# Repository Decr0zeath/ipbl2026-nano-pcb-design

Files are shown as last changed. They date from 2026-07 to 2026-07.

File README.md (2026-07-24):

# Nano Quadruped Robot PCB Design - iPBL 2026

A KiCad-based PCB design for servo motor control in a quadruped robot developed for the **International Project Based Learning (iPBL) 2026** program.

| Front | Side |
|---|---|
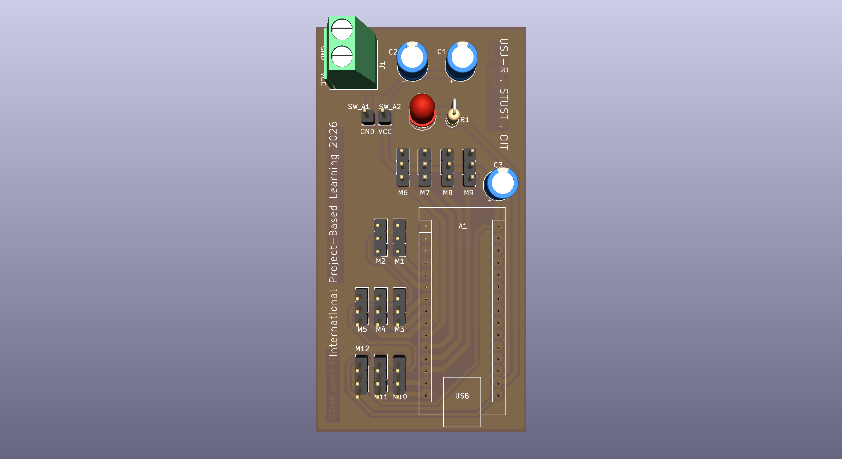
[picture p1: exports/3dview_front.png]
Expected 3D view, front
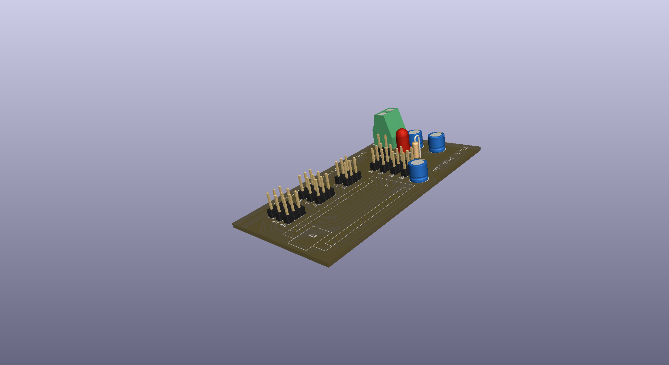
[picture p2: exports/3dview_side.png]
Expected 3D view, side
|  |  |

## Overview

This project implements a control board for mapping and managing connections to 12 servo motors used in a quadruped robot platform. The board provides power regulation and signal distribution for synchronized leg movement across four legs (3 servos per leg).

## Key Features

- **12 Servo Motor Connections** - Full support for all leg servos (M1-M12)
- **Power Supply Filtering** - Electrolytic capacitors for stable servo power
- **Screw Terminal Connector** - Easy connection to power input
- **Arduino-Compatible** - Compatible with Arduino Nano microcontroller platform
- **Raspberry Pi RX/TX Header** - Mounting holes for serial connection to a Raspberry Pi 4B
- **Compact Design** - Optimized PCB layout for integration into robot chassis

## Component Reference

| Reference | Component | Quantity | Purpose |
|---|---|---|---|
| A1 | Arduino Nano | 1 | Main microcontroller |
| M1-M12 | SG90 servo motor connections | 12 | Motor control for quadruped legs |
| C1, C2 | 470uF Electrolytic Capacitor | 2 | Power supply filtering |
| C3 | 100uF Electrolytic Capacitor | 1 | Power supply filtering |
| J3 | Straight 5mm Plugin Screw Terminal DB301V-5.0-2P | 1 | Power input connector |
| R1 | 330 ohm 1/4 watt Resistor | 1 | Current limiting for LED |
| D1 | LED | 1 | Power/status indicator |
| H1, H2 | Mounting holes | 2 | Jumper wire power switch |
| H3, H4 | Mounting holes | 2 | RX/TX connection from Nano to another microcontroller (Raspberry Pi 4B) |

## Servo Motor Configuration

The 12 servos are organized by quadruped legs:
- **Front Left Leg**: M1, M2, M3
- **Front Right Leg**: M4, M5, M6
- **Rear Left Leg**: M7, M8, M9
- **Rear Right Leg**: M10, M11, M12

## Board Views

Shown in color (rather than plain black) so they stay readable against GitHub's dark theme.

| Front Silkscreen | Bottom Copper Layer |
|---|---|
| Front silkscreen | Bottom copper layer |

### Schematic

Schematic

## Design Specifications

- **PCB Layers**: 2-layer design
- **Pad Drill Size**: Standard 0.4mm
- **Track Width**: 0.25mm (default)
- **Via Diameter**: 0.6mm / 0.4mm drill
- **Design Rules**: Checked for clearance and connectivity

## Files

- `nano_IPBL_2026.kicad_sch` - Schematic design
- `nano_IPBL_2026.kicad_pcb` - PCB layout
- `nano_IPBL_2026.kicad_pro` - KiCad project file
- `nano_IPBL_2026.kicad_prl` - Project runtime library
- `exports/nano_IPBL_2026_schematic.svg` - Full schematic view
- `exports/nano_IPBL_2026-F_Silkscreen_colored.svg` - Front silkscreen view, colored (`*_black.svg` for plain black)
- `exports/nano_IPBL_2026-B_Cu_colored.svg` - Bottom copper layer, colored (`*_black.svg` for plain black)
- `exports/3dview_front.png` / `exports/3dview_side.png` - Expected 3D renders of the board

## Getting Started

### Prerequisites
- KiCad 10.0+ (used for design and editing)
- Compatible microcontroller (Arduino Nano recommended)
- Servo motors with standard 3-wire connectors
- Power supply (typical: 5-6V for servo operation)

### Opening the Project
1. Open KiCad
2. File → Open → Select `nano_IPBL_2026.kicad_pro`
3. Double-click to view the schematic or layout

### Fabrication
- Generate Gerber files from `nano_IPBL_2026.kicad_pcb` for PCB manufacturing
- Use the included design rules for manufacturing tolerances
- Standard 2-layer PCB process compatible

## Power Budget

- **Power Source**: 2x 3.7V AA batteries in series (7.4V total)
- **Voltage Regulation**: External XL4015E1 buck converter steps down 7.4V to 5V (not part of the PCB)
- **Servo Motor Draw**: ~100-500mA per servo (depending on load)
- **Total Potential Draw**: Up to 6A for all 12 servos

## Notes

- Lock files (.lck) are not included in version control (ignored by .gitignore)
- SVG layer exports provide visual reference of copper traces
- Design includes DRC (Design Rule Check) exclusions for known non-critical issues
- All servo connections use standard 3-wire Futaba/HiTec/JR connectors

## Credits

This design is based on the original [Quadruped Spider Robot (3D Printed Parts, SG90 Servo Motor, Arduino Nano)](https://www.pcbway.com/project/shareproject/Quadruped_Spider_Robot_3D_Printed_Parts_SG90_Servo_Motor_Arduino_Nano_10107fe3.html) project shared on PCBWay. This repository branches off that design with improvements including revised switch/regulator ordering, larger vias and copper pads, and a rearranged component layout.

## License

Part of iPBL 2026 International Project Based Learning Program

---

*Last updated: 2026-07-21*

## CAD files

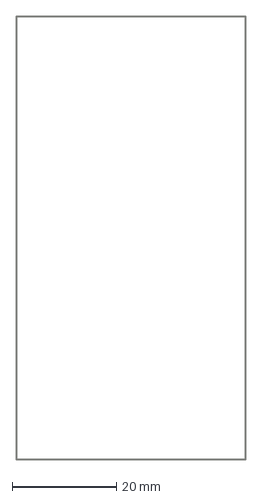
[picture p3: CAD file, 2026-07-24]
exports/dxf/nano_IPBL_2026-Edge_Cuts.dxf
44.1 x 85.1 mm

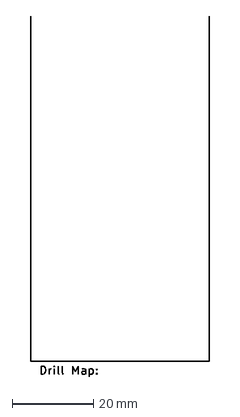
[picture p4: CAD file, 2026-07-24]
exports/dxf/nano_IPBL_2026-NPTH-drl_map.dxf
44.0 x 88.8 mm

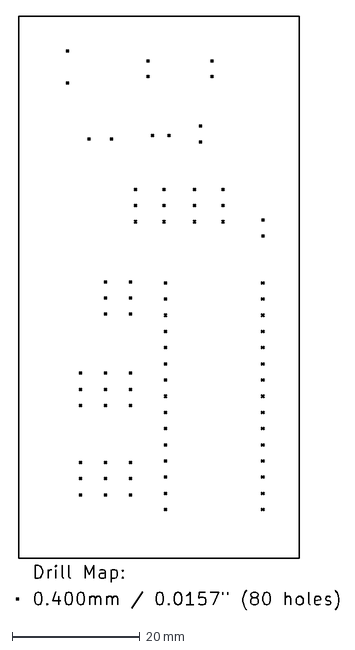
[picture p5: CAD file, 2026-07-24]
exports/dxf/nano_IPBL_2026-PTH-drl_map.dxf
50.6 x 93.1 mm

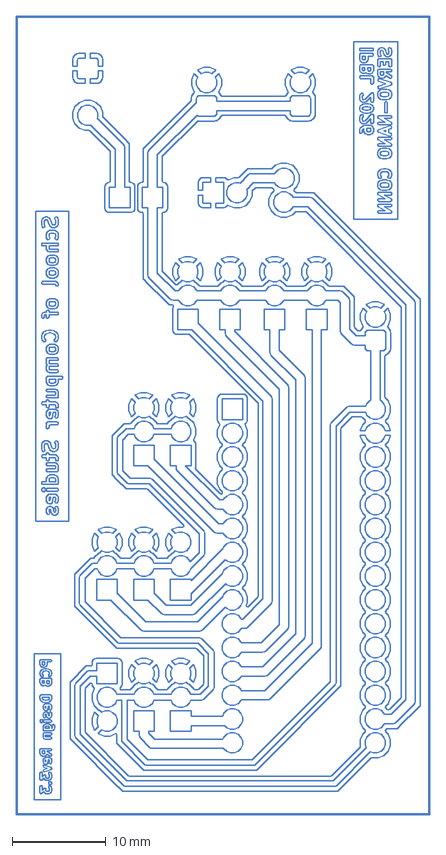
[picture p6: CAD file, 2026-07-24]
exports/dxf/nano_IPBL_2026-B_Cu.dxf
44.1 x 85.1 mm

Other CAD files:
exports/dxf/nano_IPBL_2026-B_Mask.dxf
exports/dxf/nano_IPBL_2026-F_Silkscreen.dxf

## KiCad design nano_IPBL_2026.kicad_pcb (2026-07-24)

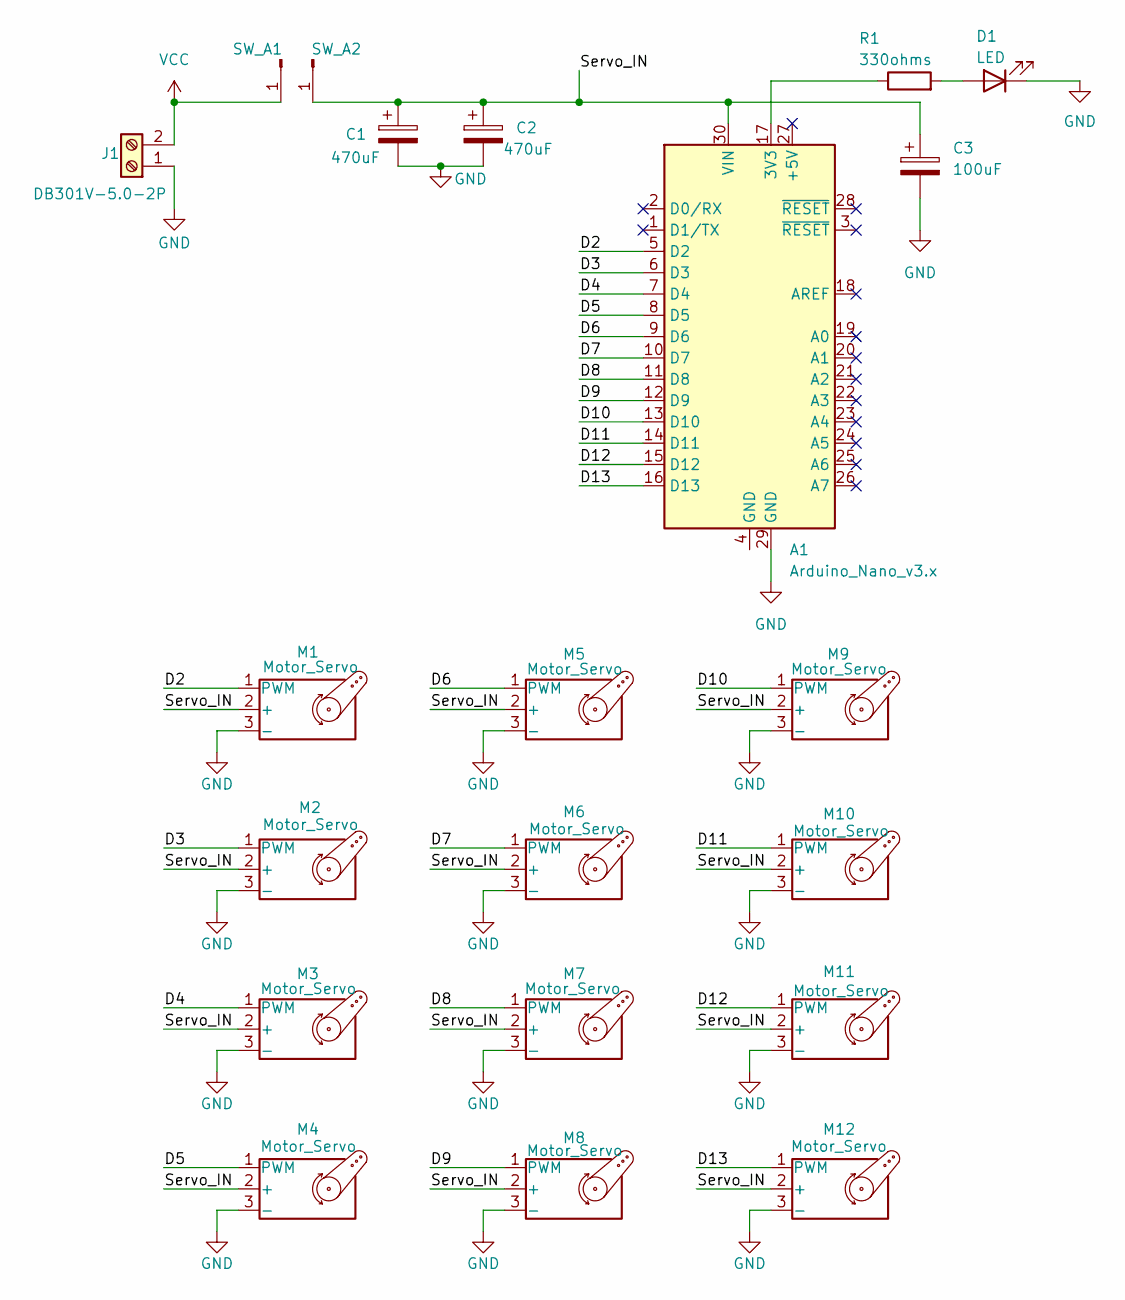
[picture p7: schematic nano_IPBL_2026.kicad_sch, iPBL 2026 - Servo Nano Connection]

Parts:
A1: Arduino_Nano_v3.x; Arduino_Nano
C1, C2: 470uF; CP_Radial_D6.3mm_P2.50mm
C3: 100uF; CP_Radial_D6.3mm_P2.50mm
D1: LED; LED_D5.0mm
J1: DB301V-5.0-2P; TerminalBlock_Phoenix_MKDS-1,5-2_1x02_P5.00mm_Horizontal; LCSC Part C395882
M1, M2, M3, M4, M5, M6, M7, M8, M9, M10, M11, M12: Motor_Servo; PinHeader_1x03_P2.54mm_Vertical
R1: 330ohms; R_Axial_DIN0207_L6.3mm_D2.5mm_P2.54mm_Vertical
SW_A1, SW_A2: Conn_01x01_Pin; PinHeader_1x01_P2.54mm_Vertical

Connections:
/D2: A1.5 (D2), M1.1 (PWM)
/D3: A1.6 (D3), M2.1 (PWM)
/D4: A1.7 (D4), M3.1 (PWM)
/D5: A1.8 (D5), M4.1 (PWM)
/D6: A1.9 (D6), M5.1 (PWM)
/D7: A1.10 (D7), M6.1 (PWM)
/D8: A1.11 (D8), M7.1 (PWM)
/D9: A1.12 (D9), M8.1 (PWM)
/D10: A1.13 (D10), M9.1 (PWM)
/D11: A1.14 (D11), M10.1 (PWM)
/D12: A1.15 (D12), M11.1 (PWM)
/D13: A1.16 (D13), M12.1 (PWM)
/Servo_IN: A1.30 (VIN), C1.1, C2.1, C3.1, M1.2 (+), M2.2 (+), M3.2 (+), M4.2 (+), M5.2 (+), M6.2 (+), M7.2 (+), M8.2 (+), M9.2 (+), M10.2 (+), M11.2 (+), M12.2 (+), SW_A2.1 (Pin_1_1)
GND: A1.29 (GND), C1.2, C2.2, C3.2, D1.1 (K), J1.1, M1.3 (-), M2.3 (-), M3.3 (-), M4.3 (-), M5.3 (-), M6.3 (-), M7.3 (-), M8.3 (-), M9.3 (-), M10.3 (-), M11.3 (-), M12.3 (-)
unnamed: A1.17 (3V3), R1.1
unnamed: D1.2 (A), R1.2
VCC: J1.2, SW_A1.1 (Pin_1_1)

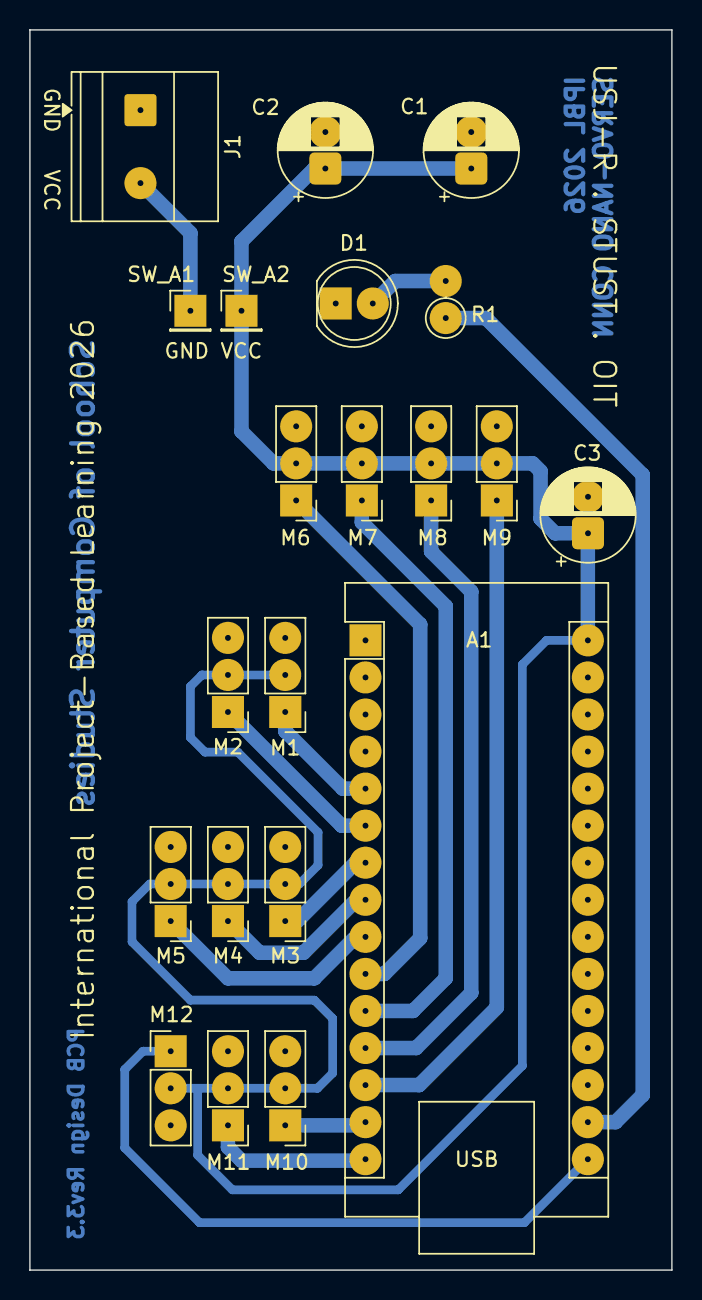
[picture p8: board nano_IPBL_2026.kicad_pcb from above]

Board: 2 copper layers, 44.0 x 85.0 mm, 21 parts (0 on the bottom side), 17 nets.

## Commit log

2026-07-10 Initial commit - PBB Design
    [nano_IPBL_2026.dsn, nano_IPBL_2026.kicad_pcb, nano_IPBL_2026.kicad_sch]
2026-07-13 Changed padding drill sizes and exported copper layer as SVG
    [nano_IPBL_2026.kicad_pcb, nano_IPBL_2026.kicad_sch]
2026-07-17 Add project documentation and layer exports
    - Add comprehensive README with project overview, hardware specs, and servo configuration
    - Add .gitignore to exclude .history directory
    - Export copper layers as SVG (front and bottom)
    - Remove .history from version control
2026-07-17 Refine PCB design and power circuit
    - Fix switch connection to come before voltage regulator (stepdown)
    - Increase via diameter to 1mm for better current distribution
    - Add 0.25mm copper pad diameter with 0.4mm drill holes
    - Rearrange component placement for improved PCB layout
    [nano_IPBL_2026.kicad_pcb, nano_IPBL_2026.kicad_sch]
2026-07-17 Remove KiCad lock files and old copper layer export
2026-07-17 Add board images and credits to README, ignore KiCad lock files
    - Show 3D render, front silkscreen, and bottom copper views in README
    - Rename exports to match KiCad output names and add 3D PNG render
    - Credit original PCBWay Quadruped Spider Robot project
    - Ignore ~*.lck KiCad lock files
2026-07-17 Remove laserprint.docx
2026-07-17 Update KiCad plot directory to exports/
2026-07-20 Remove step-down regulator and switch, add RX/TX mounting pads
    Replace the switch with a mounting pad, remove the step-down regulator,
    and add mounting pad connections for RX/TX. Reposition components to
    fit the actual enclosure, and move the 100uF capacitor closer to the Nano.
    [nano_IPBL_2026.kicad_pcb, nano_IPBL_2026.kicad_sch]
2026-07-20 Update exports for new layout, add mask/edge-cuts exports and laser print doc
2026-07-21 Adjust track width and copper clearance, match solder mask to copper pad width
    Update silkscreen text and drill hole visibility on B_Cu/F_Silkscreen layers.
    [nano_IPBL_2026.kicad_pcb, nano_IPBL_2026.kicad_sch]
2026-07-21 Update SVG exports to reflect track/clearance and silkscreen changes
2026-07-21 Update plot layer selection in PCB plot settings
    [nano_IPBL_2026.kicad_pcb]
2026-07-21 Use inverted layer exports and new 3D views in README
    Add inverted (light-on-dark) SVG exports of the bottom copper and
    front silkscreen layers so the board renders legibly against GitHub's
    dark theme, and reference them from the README board views table.
    Replace the single 3D render with separate front and side views, and
    refresh the B_Cu, Edge_Cuts and F_Silkscreen exports.
2026-07-22 Set solder mask margin to 0.1mm, drop zone min clearance
    Change solder_mask_margin from 0 to 0.1mm on all 82 pads so the mask
    openings sit slightly proud of the copper.
    Set the default zone min_clearance to 0.0mm, letting copper pours rely
    on the netclass clearance rules instead of a zone-local minimum.
    [nano_IPBL_2026.kicad_pcb]
2026-07-22 Add schematic export and show it in README
2026-07-22 Add background color to schematic export
2026-07-22 Document battery power source and external buck converter
2026-07-22 Specify XL4015E1 as the external buck converter
2026-07-23 Update PCB design to revision 3.3 and schematic to revision 2.1
    - Remove RX/TX mounting holes from schematic
    - Prepare for servo pin net label updates
    [nano_IPBL_2026.kicad_pcb, nano_IPBL_2026.kicad_sch]
2026-07-23 Export Gerber files for PCB revision 3.3
    [nano_IPBL_2026-B_Cu.gbl, nano_IPBL_2026-Edge_Cuts.gm1, nano_IPBL_2026-F_Cu.gtl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]
2026-07-24 Add net labels to schematic for improved readability
    [nano_IPBL_2026.kicad_pcb, nano_IPBL_2026.kicad_sch]
2026-07-24 Update screw terminal footprint and replace SW_A1/SW_B1 mounting holes with header
    Screw terminal footprint now includes its 3D model counterpart. SW_A1
    and SW_B1 mounting holes replaced with a 1-pin connected header.
    Copper/silkscreen layer view colors changed from inverted to colored.
    [nano_IPBL_2026.kicad_pcb, nano_IPBL_2026.kicad_sch]
2026-07-24 Regenerate exports and update README for colored/black SVG naming
    Schematic SVG, 3D views, and gerbers regenerated for the latest
    design. Copper/silkscreen SVG exports renamed to _colored/_black
    instead of the previous plain/_inverted scheme; README updated to
    match.
    [nano_IPBL_2026-B_Cu.gbl, nano_IPBL_2026-B_Mask.gbs, nano_IPBL_2026-Edge_Cuts.gm1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]
2026-07-24 Add DXF exports of copper, mask, silkscreen, and edge cuts with drill files
    [nano_IPBL_2026-B_Cu.dxf, nano_IPBL_2026-B_Mask.dxf, nano_IPBL_2026-Edge_Cuts.dxf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]
2026-07-24 Update laserprint documentation export
